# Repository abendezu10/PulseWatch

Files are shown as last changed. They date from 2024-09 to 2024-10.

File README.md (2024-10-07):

# PulseWatch
A Smart Watch that uses the STM32L4

## Schematic


## Printed Circuit Board (PCB)


## 3D Model


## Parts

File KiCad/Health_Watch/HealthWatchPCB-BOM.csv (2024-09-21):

Reference | Value | Footprint | Distrubutor Link | Manufacturer | Manufacturer Part Number
J4 | Conn_01x11 | Connector_PinHeader_1.00mm:01x10_Conn_Hole
SW1 | SW_Omron_B3FS | Button_Switch_THT:SW_TH_Tactile_Omron_B3F-10xx
J1 | JST-PH-Conn | Health_Watch:CONN_S2B-PH-K-S_JST | https://www.digikey.com/en/products/detail/jst-sales-america-inc/S2B-PH-K-S/926626 | JST Sales America Inc. | S2B-PH-K-S
U1 | MCP73831-2-OT | Package_TO_SOT_SMD:SOT-23-5 | https://www.mouser.com/ProductDetail/Microchip-Technology/MCP73831T-2ACI-OT?qs=yUQqVecv4qvbBQBGbHx0Mw%3D%3D | Microchip Technology | MCP73831T-2ACI/OT
D1 | D_Schottky | Diode_SMD:D_SOD-523 | https://www.mouser.com/ProductDetail/Diodes-Incorporated/ZHCS350TA?qs=%2F4dsY8i%2FUxLp1LQSBxPJBA%3D%3D | Diodes Incorporated | ZHCS350TA
C2 | 100n | Capacitor_SMD:C_0402_1005Metric | https://www.mouser.com/ProductDetail/KYOCERA-AVX/0402X7R104KT7AT?qs=DPoM0jnrROXD467pFR2ukA%3D%3D | KYOCERA AVX | 0402X7R104KT7AT
C3 | 100n | Capacitor_SMD:C_0402_1005Metric | https://www.mouser.com/ProductDetail/KYOCERA-AVX/0402X7R104KT7AT?qs=DPoM0jnrROXD467pFR2ukA%3D%3D | KYOCERA AVX | 0402X7R104KT7AT
C4 | 100n | Capacitor_SMD:C_0402_1005Metric | https://www.mouser.com/ProductDetail/KYOCERA-AVX/0402X7R104KT7AT?qs=DPoM0jnrROXD467pFR2ukA%3D%3D | KYOCERA AVX | 0402X7R104KT7AT
C5 | 100n | Capacitor_SMD:C_0402_1005Metric | https://www.mouser.com/ProductDetail/KYOCERA-AVX/0402X7R104KT7AT?qs=DPoM0jnrROXD467pFR2ukA%3D%3D | KYOCERA AVX | 0402X7R104KT7AT
C6 | 100n | Capacitor_SMD:C_0402_1005Metric | https://www.mouser.com/ProductDetail/KYOCERA-AVX/0402X7R104KT7AT?qs=DPoM0jnrROXD467pFR2ukA%3D%3D | KYOCERA AVX | 0402X7R104KT7AT
C11 | 100n | Capacitor_SMD:C_0402_1005Metric | https://www.mouser.com/ProductDetail/KYOCERA-AVX/0402X7R104KT7AT?qs=DPoM0jnrROXD467pFR2ukA%3D%3D | KYOCERA AVX | 0402X7R104KT7AT
C12 | 20p | Capacitor_SMD:C_0402_1005Metric | https://www.mouser.com/ProductDetail/KEMET/C0402C200F5GACTU?qs=6j%252BeEuyKpjUVwvZ04nQbhg%3D%3D | KEMET | C0402C200F5GACTU
C13 | 20p | Capacitor_SMD:C_0402_1005Metric | https://www.mouser.com/ProductDetail/KEMET/C0402C200F5GACTU?qs=6j%252BeEuyKpjUVwvZ04nQbhg%3D%3D | KEMET | C0402C200F5GACTU
R5 | 4k7 | Resistor_SMD:R_0402_1005Metric | https://www.mouser.com/ProductDetail/Vishay-Dale/CRCW04024K70FKEDC?qs=E3Y5ESvWgWMhkkkEGGyyBQ%3D%3D | Vishay / Dale | CRCW04024K70FKEDC
R6 | 4k7 | Resistor_SMD:R_0402_1005Metric | https://www.mouser.com/ProductDetail/Vishay-Dale/CRCW04024K70FKEDC?qs=E3Y5ESvWgWMhkkkEGGyyBQ%3D%3D | Vishay / Dale | CRCW04024K70FKEDC
R4 | 10k | Resistor_SMD:R_0603_1608Metric | https://www.mouser.com/ProductDetail/Vishay-Dale/CRCW060310K0FKEI?qs=3qWEzBg5KnKofE%252B8acPBRA%3D%3D | Vishay / Dale | CRCW060310K0FKEI
R7 | 10K | Resistor_SMD:R_0603_1608Metric | https://www.mouser.com/ProductDetail/Vishay-Dale/CRCW060310K0FKEI?qs=3qWEzBg5KnKofE%252B8acPBRA%3D%3D | Vishay / Dale | CRCW060310K0FKEI
X1 | 8MHz | Crystal:Crystal_SMD_3225-4Pin_3.2x2.5mm | https://www.mouser.com/ProductDetail/ECS/ECS-2016MV-080-DN-TR?qs=3Rah4i%252BhyCF9jcrLdRF3LQ%3D%3D | ECS | ECS-2016MV-080-DN-TR
R9 | 390R | Resistor_SMD:R_0603_1608Metric | https://www.mouser.com/ProductDetail/Panasonic/ERJ-PA3F3900V?qs=BzJM0faLVqWJGJ93pXcUAw%3D%3D | Panasonic | ERJ-PA3F3900V
D2 | TVS Diode | Diode_SMD:D_SOD-923 | https://www.mouser.com/ProductDetail/onsemi/ESD9B5.0ST5G?qs=HL4IEvuNMQqfrGPZiLZXfQ%3D%3D | onsemi | ESD9B5.0ST5G
X2 | 32KHz | Crystal:Crystal_SMD_EuroQuartz_EQ161-2Pin_3.2x1.5mm | https://www.mouser.com/ProductDetail/Epson-Timing/FC-135R-32.7680KA-A3?qs=f9yNj16SXrIR19rZDPQCyw%3D%3D | Epson Timing | FC-135R 32.7680KA-A3
C1 | 4u7 | Capacitor_SMD:C_0603_1608Metric | https://www.mouser.com/ProductDetail/TAIYO-YUDEN/LMK107BJ475KA-T?qs=PzICbMaShUfCoRlxZeLF0g%3D%3D | TAIYO YUDEN | LMK107BJ475KA-T
C8 | 4u7 | Capacitor_SMD:C_0603_1608Metric | https://www.mouser.com/ProductDetail/TAIYO-YUDEN/LMK107BJ475KA-T?qs=PzICbMaShUfCoRlxZeLF0g%3D%3D | TAIYO YUDEN | LMK107BJ475KA-T
C9 | 4u7 | Capacitor_SMD:C_0603_1608Metric | https://www.mouser.com/ProductDetail/TAIYO-YUDEN/LMK107BJ475KA-T?qs=PzICbMaShUfCoRlxZeLF0g%3D%3D | TAIYO YUDEN | LMK107BJ475KA-T
C10 | 4u7 | Capacitor_SMD:C_0603_1608Metric | https://www.mouser.com/ProductDetail/TAIYO-YUDEN/LMK107BJ475KA-T?qs=PzICbMaShUfCoRlxZeLF0g%3D%3D | TAIYO YUDEN | LMK107BJ475KA-T
C14 | 10p | Capacitor_SMD:C_0402_1005Metric | https://www.mouser.com/ProductDetail/TAIYO-YUDEN/MBASU105SCH100JFNA01?qs=HFfMDpzxxd0g7wV8xJjM8Q%3D%3D | TAIYO YUDEN | MBASU105SCH100JFNA01
C15 | 10p | Capacitor_SMD:C_0402_1005Metric | https://www.mouser.com/ProductDetail/TAIYO-YUDEN/MBASU105SCH100JFNA01?qs=HFfMDpzxxd0g7wV8xJjM8Q%3D%3D | TAIYO YUDEN | MBASU105SCH100JFNA01
R1 | 5k1 | Resistor_SMD:R_0402_1005Metric | https://www.mouser.com/ProductDetail/Vishay-Beyschlag/MCS04020C5101FE000?qs=wTZ%2FFzl837YsKPLPRIXUbg%3D%3D | Vishay / Beyschlag | MCS04020C5101FE000
R2 | 5k1 | Resistor_SMD:R_0402_1005Metric | https://www.mouser.com/ProductDetail/Vishay-Beyschlag/MCS04020C5101FE000?qs=wTZ%2FFzl837YsKPLPRIXUbg%3D%3D | Vishay / Beyschlag | MCS04020C5101FE000
R3 | 5k1 | Resistor_SMD:R_0402_1005Metric | https://www.mouser.com/ProductDetail/Vishay-Beyschlag/MCS04020C5101FE000?qs=wTZ%2FFzl837YsKPLPRIXUbg%3D%3D | Vishay / Beyschlag | MCS04020C5101FE000
U2 | MIC5365-3.3YD5 | Package_TO_SOT_SMD:SOT-23-5 | https://www.mouser.com/ProductDetail/Microchip-Technology/MIC5365-3.3YD5-TR?qs=U6T8BxXiZAXzRinbbfZRrg%3D%3D | Microchip Technology | MIC5365-3.3YD5-TR
U3 | STM32L476RGTx | Package_QFP:LQFP-64_10x10mm_P0.5mm | https://www.mouser.com/ProductDetail/STMicroelectronics/STM32L476RGT6?qs=o58qnh%2FCpu44V%252B7CaDZzCA%3D%3D | STMicroelectronics | STM32L476RGT6
C7 | 10u | Capacitor_SMD:C_0805_2012Metric | https://www.mouser.com/ProductDetail/TAIYO-YUDEN/TMK212BBJ106KG8T?qs=DPoM0jnrROXqgS%2FUkxgBrw%3D%3D | TAIYO YUDEN | TMK212BBJ106KG8T
J2 | USB_C_Receptacle_PowerOnly_6P | Connector_USB:USB_C_Receptacle_GCT_USB4125-xx-x_6P_TopMnt_Horizontal | https://www.mouser.com/ProductDetail/GCT/USB4125-GF-A?qs=KUoIvG%2F9IlaIQ4zBJ6gLeA%3D%3D | GCT | USB4125-GF-A

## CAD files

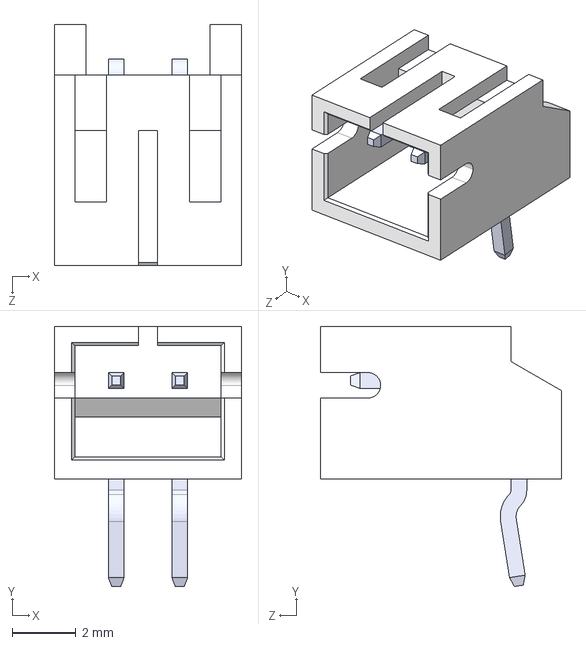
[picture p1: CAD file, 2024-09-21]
KiCad/Health-Watch Library/S2B-PH-K-S.STEP
5.90 x 8.18 x 7.60 mm

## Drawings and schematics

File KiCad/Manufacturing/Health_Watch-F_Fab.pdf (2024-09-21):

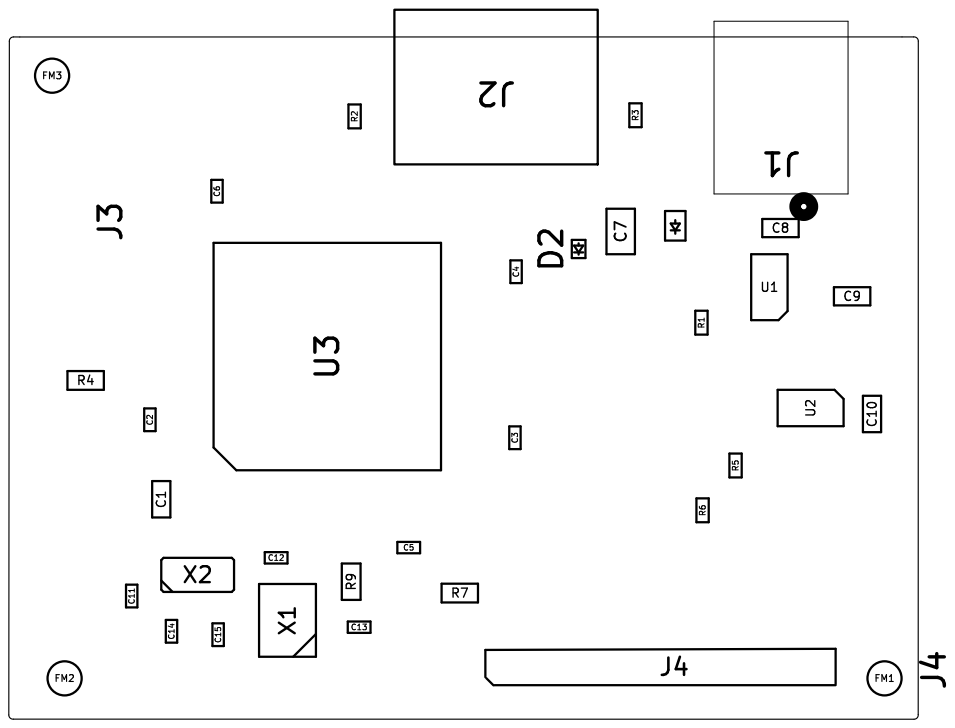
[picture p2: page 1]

Id: 1/1 Title: File: Health_Watch.kicad_pcb Sheet: R5 D2

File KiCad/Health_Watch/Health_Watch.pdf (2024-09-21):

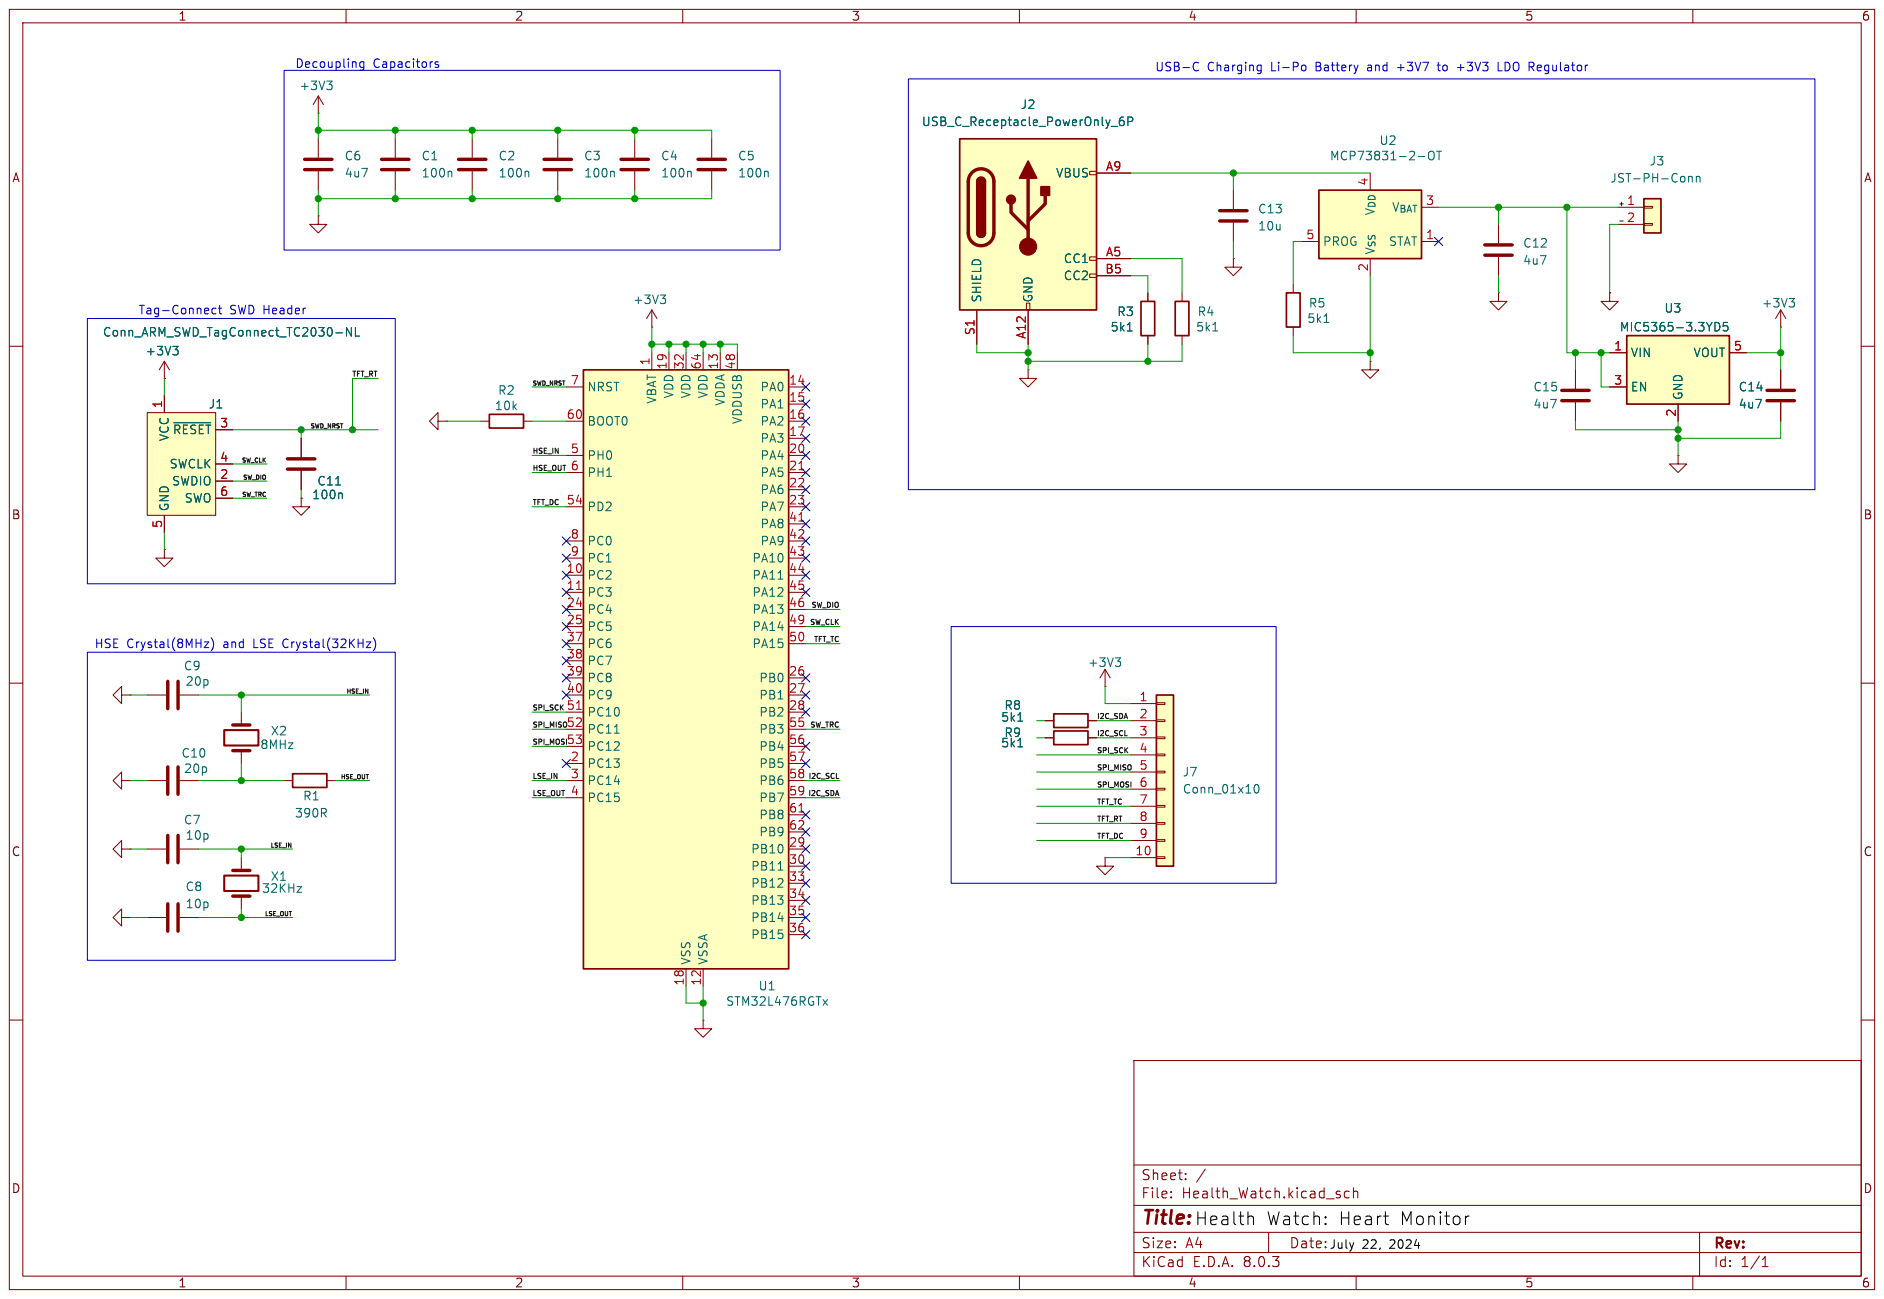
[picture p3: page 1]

1 PC2 10 PC3 11 VSSA 12 VDDA 13 PA0 14 PA1 15 PA2 16 PA3 17 VSS 18 VDD 19 PC13 2 PA4 20 PA5 21 PA6 22 PA7 23 PC4 24 PC5 25 PB0 26 PB1 27 PB2 28 PB10 29 PC14 3 PB11 30 VDD 32 PB12 33 PB13 34 PB14 35 PB15 36 PC6 37 PC7 38 PC8 39 PC15 4 PC9 40 PA8 41 PA9 42 PA10 43 PA11 44 PA12 45 PA13 46 VDDUSB 48 PA14 49 PH0 5 PA15 50 PC10 51 PC11 52 PC12 53 PD2 54 PB3 55 PB4 56 PB5 57 PB6 58 PB7 59 PH1 6 BOOT0 60 PB8 61 PB9 62 VDD 64 NRST 7 PC0 8 PC1 9 U1 STM32L476RGTx R1

1 SWDIO 2 ~{RESET}3 SWCLK 4 GND

Id: 1/1 Title: File: Health_Watch.kicad_sch Sheet: /

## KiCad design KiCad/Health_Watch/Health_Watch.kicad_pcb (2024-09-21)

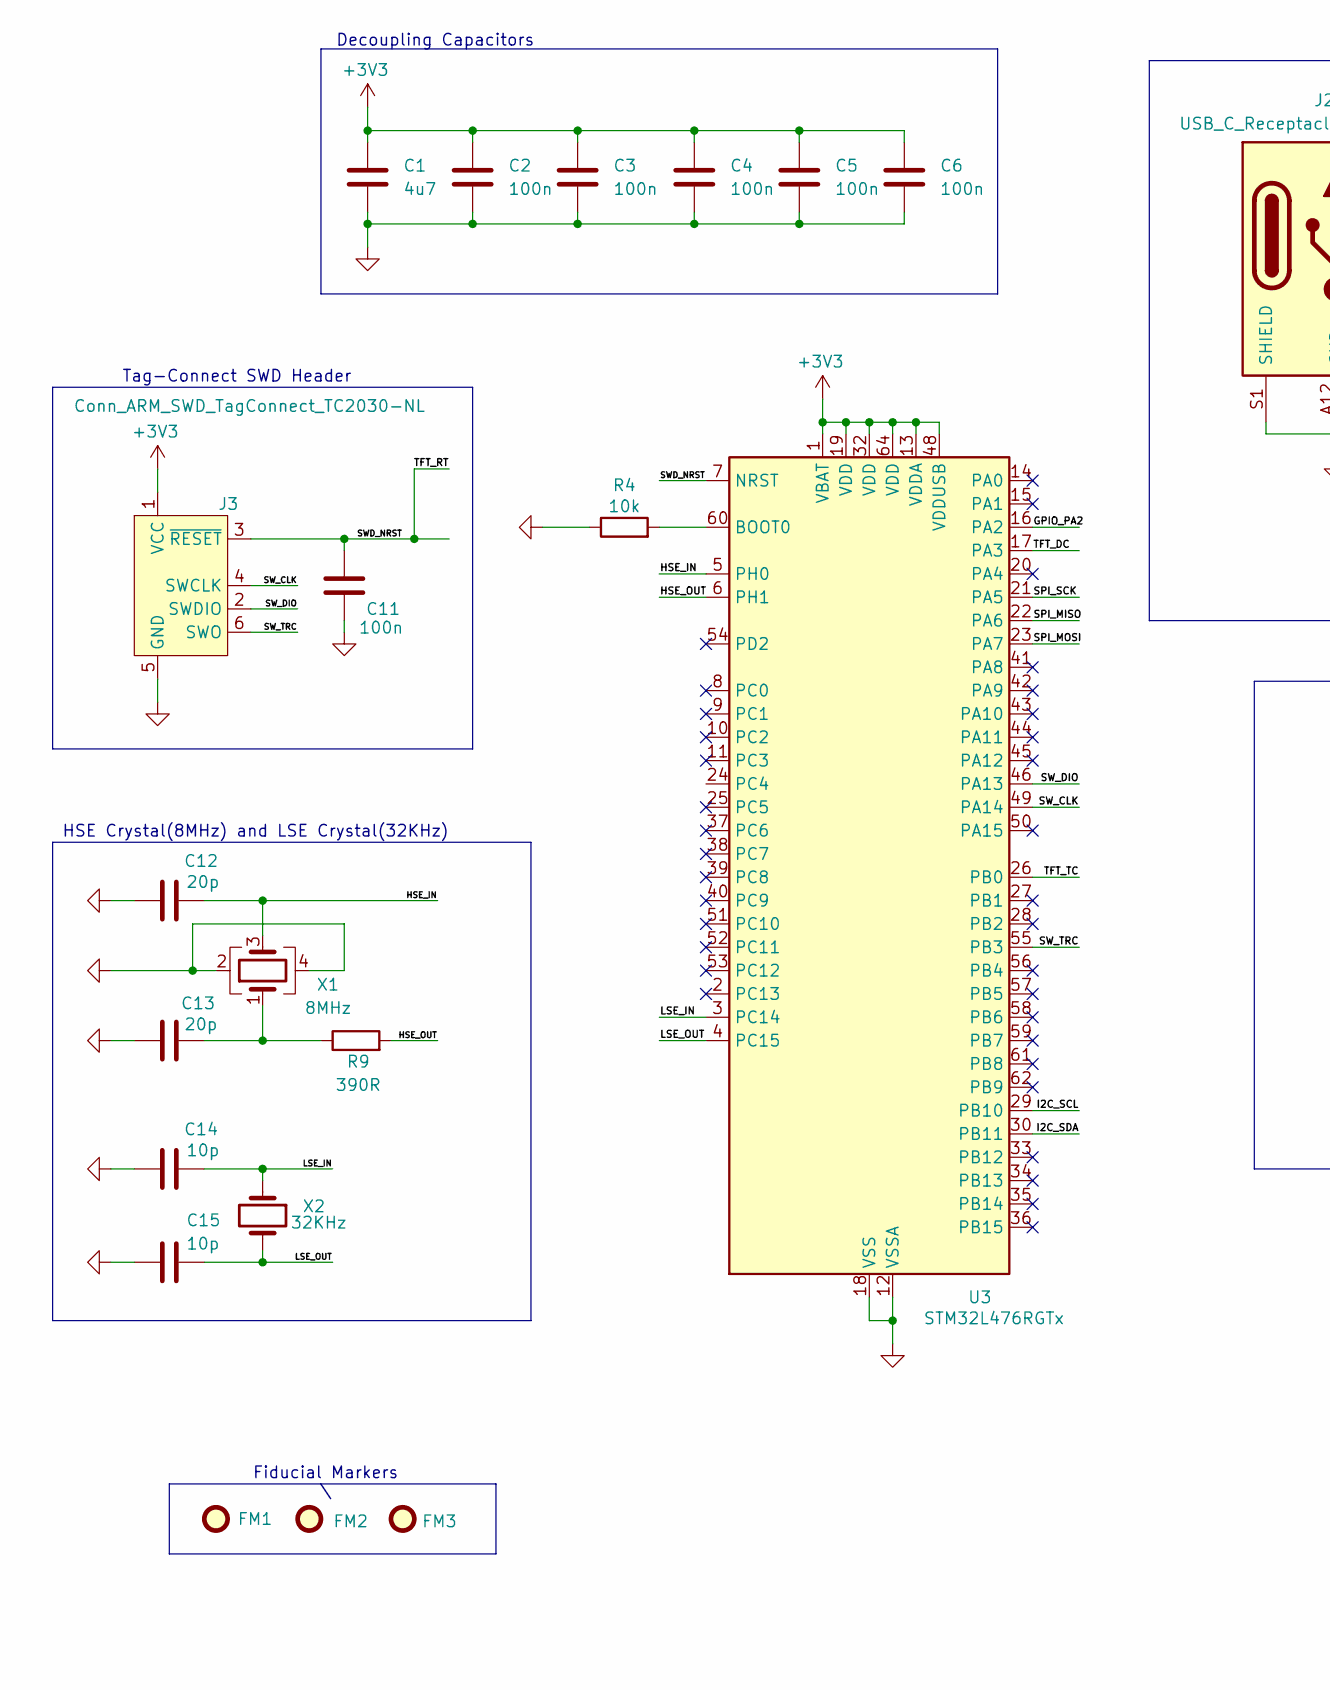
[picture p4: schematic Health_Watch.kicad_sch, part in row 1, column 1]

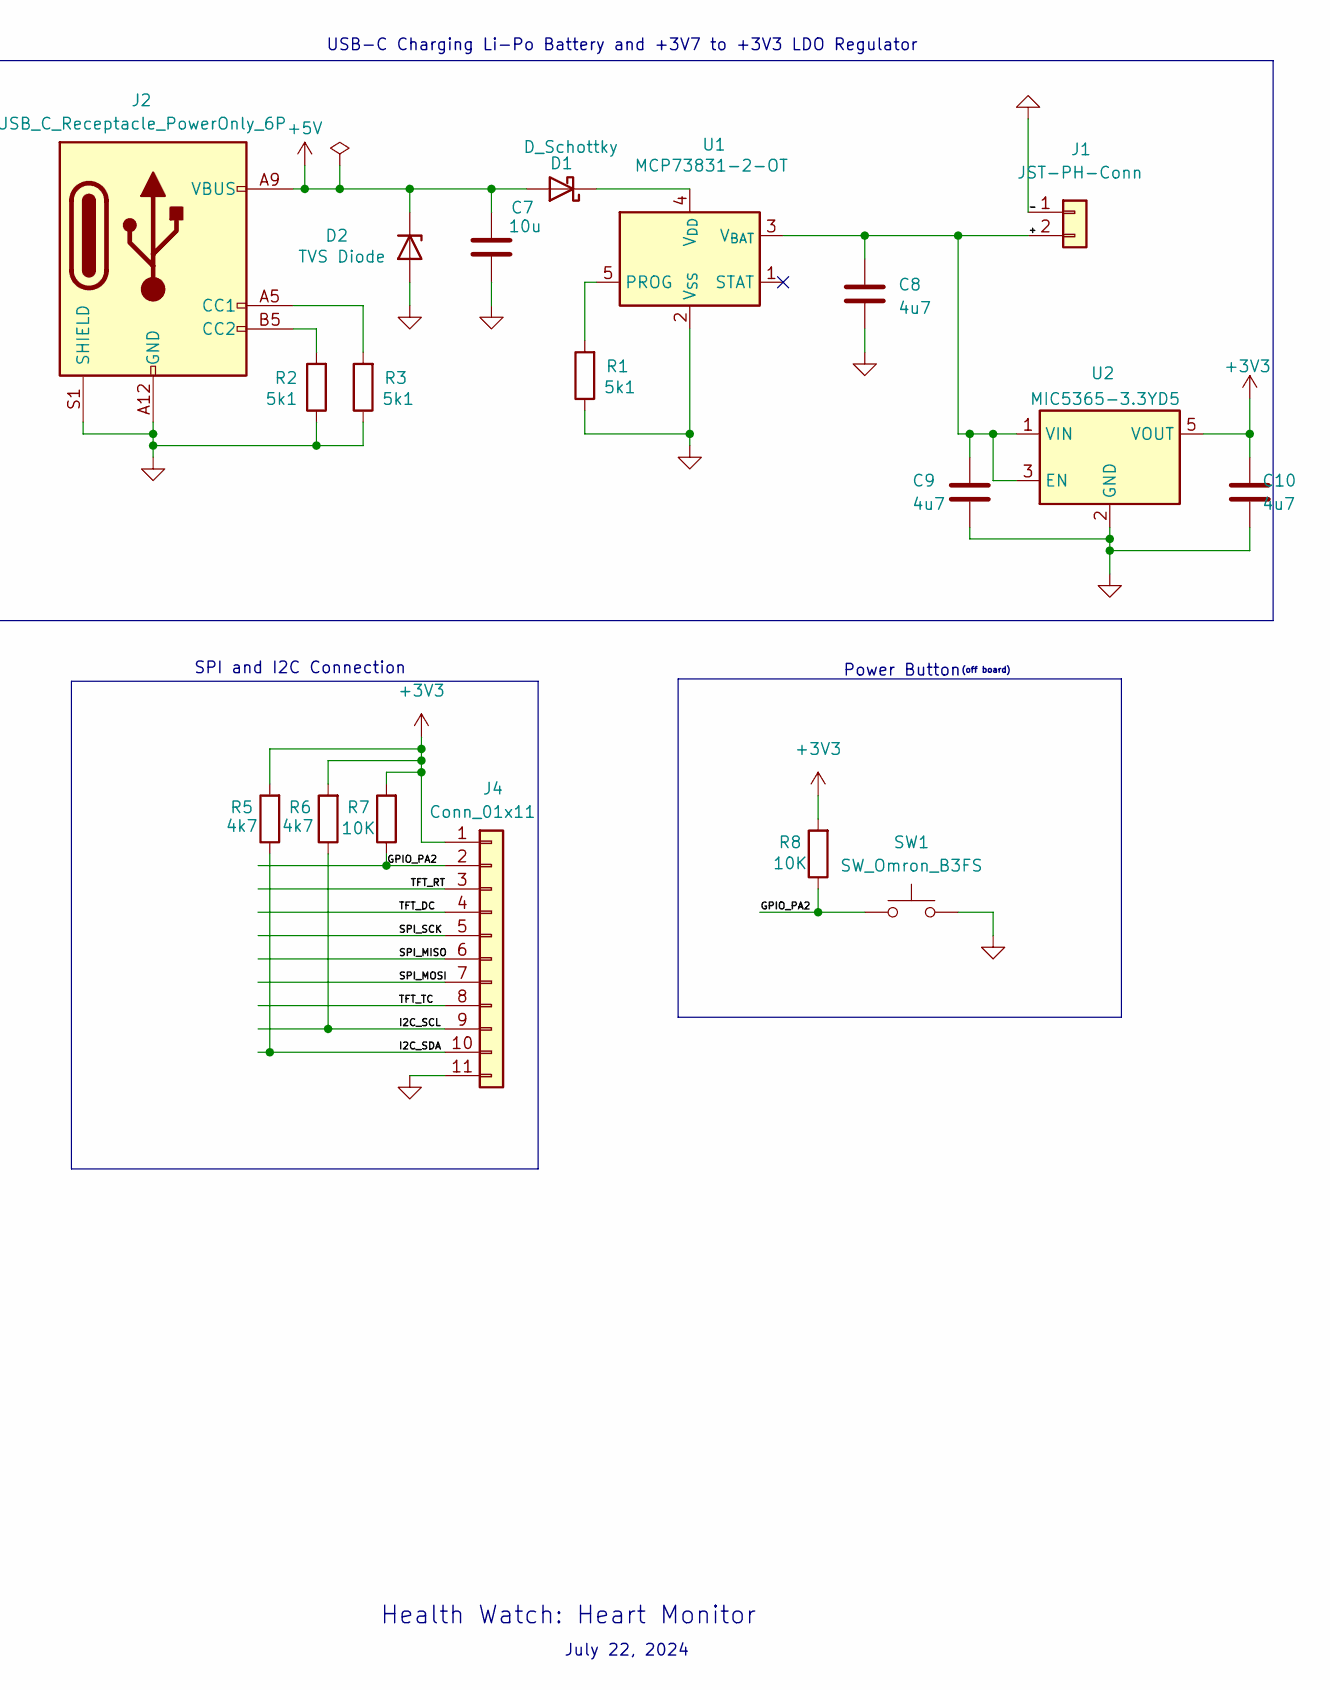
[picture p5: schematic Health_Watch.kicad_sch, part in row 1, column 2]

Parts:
C1, C8, C9, C10: 4u7; C_0603_1608Metric; Manufacturer Part Number LMK107BJ475KA-T
C2, C3, C4, C5, C6, C11: 100n; C_0402_1005Metric; Manufacturer Part Number 0402X7R104KT7AT
C7: 10u; C_0805_2012Metric; Manufacturer Part Number TMK212BBJ106KG8T
C12, C13: 20p; C_0402_1005Metric; Manufacturer Part Number C0402C200F5GACTU
C14, C15: 10p; C_0402_1005Metric; Manufacturer Part Number MBASU105SCH100JFNA01
D1: D_Schottky; D_SOD-523; Manufacturer Part Number ZHCS350TA
D2: TVS Diode; D_SOD-923; Manufacturer Part Number ESD9B5.0ST5G
FM1, FM2, FM3: Fiducial; Fiducial_0.75mm_Mask1.5mm
J1: JST-PH-Conn; CONN_S2B-PH-K-S_JST; Manufacturer Part Number S2B-PH-K-S
J2: USB_C_Receptacle_PowerOnly_6P; USB_C_Receptacle_GCT_USB4125-xx-x_6P_TopMnt_Horizontal; Manufacturer Part Number USB4125-GF-A
J3: Conn_ARM_SWD_TagConnect_TC2030-NL; Tag-Connect_TC2030-IDC-NL_2x03_P1.27mm_Vertical
J4: Conn_01x11; 01x10_Conn_Hole
R1, R2, R3: 5k1; R_0402_1005Metric; Manufacturer Part Number MCS04020C5101FE000
R4: 10k; R_0603_1608Metric; Manufacturer Part Number CRCW060310K0FKEA
R5, R6: 4k7; R_0402_1005Metric; Manufacturer Part Number CRCW04024K70FKEDC
R7: 10K; R_0603_1608Metric; Manufacturer Part Number CRCW060310K0FKEA
R8: 10K; R_0603_1608Metric
R9: 390R; R_0603_1608Metric; Manufacturer Part Number ERJ-PA3F3900V
SW1: SW_Omron_B3FS; SW_TH_Tactile_Omron_B3F-10xx
U1: MCP73831-2-OT; SOT-23-5; Manufacturer Part Number MCP73831T-2ACI/OT
U2: MIC5365-3.3YD5; SOT-23-5; Manufacturer Part Number MIC5365-3.3YD5-TR
U3: STM32L476RGTx; LQFP-64_10x10mm_P0.5mm; Manufacturer Part Number STM32L476RGT6
X1: 8MHz; Crystal_SMD_3225-4Pin_3.2x2.5mm; Manufacturer Part Number ECS-2016MV-080-DN-TR
X2: 32KHz; Crystal_SMD_EuroQuartz_EQ161-2Pin_3.2x1.5mm; Manufacturer Part Number FC-135R 32.7680KA-A3

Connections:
+3V3: C1.1, C2.1, C3.1, C4.1, C5.1, C6.1, C10.1, J3.1 (VCC), J4.1, R5.2, R6.2, R7.2, R8.2, U2.5 (VOUT), U3.1 (VBAT), U3.13 (VDDA), U3.19 (VDD), U3.32 (VDD), U3.48 (VDDUSB), U3.64 (VDD)
+5V: C7.1, D1.2 (A), D2.1 (K), J2.A9 (VBUS), J2.B9 (VBUS)
/+: C8.1, C9.1, J1.2, U1.3 (V_{BAT}), U2.1 (VIN), U2.3 (EN)
/GPIO_PA2: J4.2, R7.1, R8.1, SW1.1, U3.16 (PA2)
/HSE_IN: C12.1, U3.5 (PH0), X1.3
/HSE_OUT: R9.2, U3.6 (PH1)
/I2C_SCL: J4.9, R6.1, U3.29 (PB10)
/I2C_SDA: J4.10, R5.1, U3.30 (PB11)
/LSE_IN: C14.1, U3.3 (PC14), X2.1
/LSE_OUT: C15.1, U3.4 (PC15), X2.2
/SPI_MISO: J4.6, U3.22 (PA6)
/SPI_MOSI: J4.7, U3.23 (PA7)
/SPI_SCK: J4.5, U3.21 (PA5)
/SWD_NRST: C11.1, J3.3 (~RESET), J4.3, U3.7 (NRST)
/SW_CLK: J3.4 (SWCLK), U3.49 (PA14)
/SW_DIO: J3.2 (SWDIO), U3.46 (PA13)
/SW_TRC: J3.6 (SWO), U3.55 (PB3)
/TFT_DC: J4.4, U3.17 (PA3)
/TFT_TC: J4.8, U3.26 (PB0)
GND: C1.2, C2.2, C3.2, C4.2, C5.2, C6.2, C7.2, C8.2, C9.2, C10.2, C11.2, C12.2, C13.1, C14.2, C15.2, D2.2 (A), J1.1, J2.A12 (GND), J2.B12 (GND), J2.S1 (SHIELD), J3.5 (GND), J4.11, R1.1, R2.1, R3.1, R4.1, SW1.2, U1.2 (V_{SS}), U2.2 (GND), U3.12 (VSSA), U3.18 (VSS), U3.31 (VSS), U3.47 (VSS), U3.63 (VSS), X1.2, X1.4
unnamed: C13.2, R9.1, X1.1
unnamed: D1.1 (K), U1.4 (V_{DD})
unnamed: J2.A5 (CC1), R3.2
unnamed: J2.B5 (CC2), R2.2
unnamed: R1.2, U1.5 (PROG)
unnamed: R4.2, U3.60 (BOOT0)

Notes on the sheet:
Decoupling Capacitors
(off board)
Health Watch: Heart Monitor
Tag-Connect SWD Header
USB-C Charging Li-Po Battery and +3V7 to +3V3 LDO Regulator
Power Button
SPI and I2C Connection
HSE Crystal(8MHz) and LSE Crystal(32KHz)
July 22, 2024
Fiducial Markers \

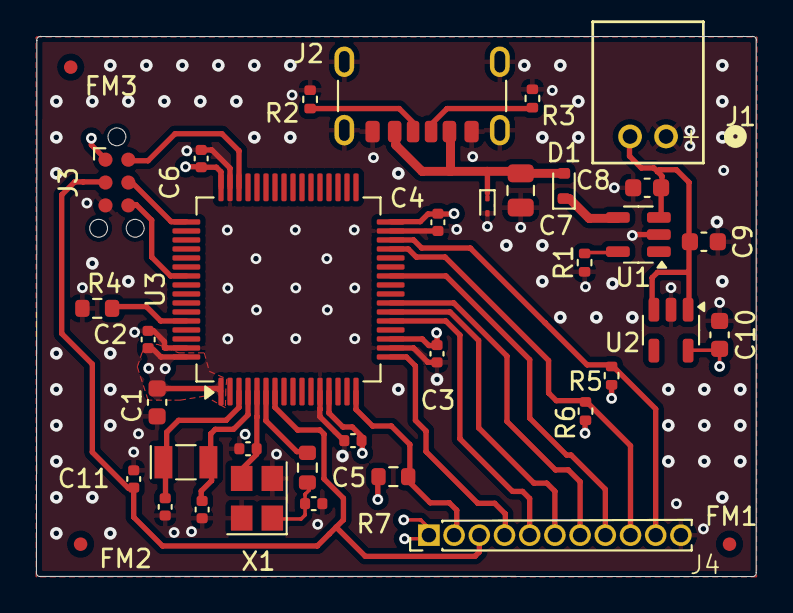
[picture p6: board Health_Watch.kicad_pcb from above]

Board: 4 copper layers, 40.0 x 30.0 mm, 37 parts (0 on the bottom side), 26 nets.

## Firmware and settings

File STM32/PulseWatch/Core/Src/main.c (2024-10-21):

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
/* Includes ------------------------------------------------------------------*/
#include "main.h"
#include "max30102_for_stm32_hal.h"

#include <string.h>

I2C_HandleTypeDef hi2c1;

UART_HandleTypeDef huart2;

// printf() function
int __io_putchar(int ch)
{
  uint8_t temp = ch;
  HAL_UART_Transmit(&huart2, &temp, 1, HAL_MAX_DELAY);
  return ch;
}

// Override plot function
void max30102_plot(uint32_t ir_sample, uint32_t red_sample)
{
    // printf("ir:%u\n", ir_sample);                  // Print IR only
    // printf("r:%u\n", red_sample);                  // Print Red only
    printf("ir:%u,r:%u\n", ir_sample, red_sample);    // Print IR and Red
}

// MAX30102 object
max30102_t max30102;

void SystemClock_Config(void);
static void MX_GPIO_Init(void);
static void MX_I2C1_Init(void);
static void MX_USART2_UART_Init(void);
/**
  * @brief  The application entry point.
  * @retval int
  */
int main(void)
{

	  /* MCU Configuration--------------------------------------------------------*/

	  /* Reset of all peripherals, Initializes the Flash interface and the Systick. */
	  HAL_Init();

	  /* Configure the system clock */
	  SystemClock_Config();

	  /* Initialize all configured peripherals */
	  MX_GPIO_Init();
	  MX_I2C1_Init();
	  MX_USART2_UART_Init();
	  /* USER CODE BEGIN 2 */
	  // Initiation
	  max30102_init(&max30102, &hi2c1);
	  max30102_reset(&max30102);
	  max30102_clear_fifo(&max30102);
	  max30102_set_fifo_config(&max30102, max30102_smp_ave_8, 1, 7);

	  // Sensor settings
	  max30102_set_led_pulse_width(&max30102, max30102_pw_16_bit);
	  max30102_set_adc_resolution(&max30102, max30102_adc_2048);
	  max30102_set_sampling_rate(&max30102, max30102_sr_800);
	  max30102_set_led_current_1(&max30102, 6.2);
	  max30102_set_led_current_2(&max30102, 6.2);

	  // Enter SpO2 mode
	  max30102_set_mode(&max30102, max30102_spo2);
	  max30102_set_a_full(&max30102, 1);

	  // Initiate 1 temperature measurement
	  max30102_set_die_temp_en(&max30102, 1);
	  max30102_set_die_temp_rdy(&max30102, 1);

	  uint8_t en_reg[2] = {0};
	  max30102_read(&max30102, 0x00, en_reg, 1);
	  /* USER CODE END 2 */

	  /* Infinite loop */
	  /* USER CODE BEGIN WHILE */
	  while (1)
	  {



	    if (max30102_has_interrupt(&max30102))
	    {
	      max30102_interrupt_handler(&max30102);
	    }
	    /* USER CODE END WHILE */

	    /* USER CODE BEGIN 3 */
	  }
	  /* USER CODE END 3 */
}

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


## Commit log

2024-07-22 adding KiCad Project
    [Health_Watch.kicad_pcb, Health_Watch.kicad_sch]
2024-07-23 Updated Schematic KiCad
    [Health_Watch.kicad_sch]
2024-09-21 adding schematic and PCB layout
    [HealthWatchPCB-BOM.csv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]
2024-09-22 added stm32 project
    [HealthWatchPCB-BOM.csv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]
2024-10-21 added new stm32 project

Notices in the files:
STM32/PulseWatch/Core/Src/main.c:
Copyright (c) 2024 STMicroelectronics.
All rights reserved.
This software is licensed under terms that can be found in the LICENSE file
